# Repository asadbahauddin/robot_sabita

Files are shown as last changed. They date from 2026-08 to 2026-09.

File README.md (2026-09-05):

# SABITA - Robot Pemandu Pameran

Robot line-follower pemandu pameran lukisan (6 karya di node A-F), navigasi
lewat scan QR + rute optimal ACO (Ant Colony Optimization), line-follower
PID adaptif, audio narasi per karya (DFPlayer Mini).

## Arsitektur

Sejak v10, ESP32 **tidak lagi menyajikan HTML**. Semua dashboard/UI pindah
ke laptop supaya beban ESP32 minimal (hanya WiFi AP + WebSocket + motor + sensor).

```
[Sensor S1-S4,S6 (digital), GM67 QR, DFPlayer]
            |
         ESP32  (WiFi AP: SABITA_ROBOT / 12345678)
            |  WebSocket ws://192.168.4.1:81  (data sensor/nav/state/qr/dfp,
            |                                   perintah motor/PID/tuning)
            v
   tools/sabita_server.py   (laptop, relay + serve dashboard + log CSV)
            |  WebSocket ws://localhost:8080/ws
            v
   tools/dashboard.html      (browser laptop: peta, sensor, grafik PID, tuning)
```

`simulasi/` berisi alat terpisah (offline): simulasi rute ACO (GIF) dan
live-monitor alternatif berbasis Python/matplotlib untuk debugging line-follower
langsung dari WebSocket ESP32 tanpa perlu dashboard.html. Lihat bagian
[Alat tambahan](#alat-tambahan-simulasi) di bawah.

## Cara pakai

### 1. Upload firmware ke ESP32

Buka `robot_sabita.ino` di Arduino IDE, pilih board ESP32 yang sesuai, upload.
Pastikan tidak ada file `.ino` lain di folder yang sama (Arduino menggabungkan
semua `.ino` di folder sketch jadi satu build -- itu sebabnya backup lama
disimpan di `backup/*.ino.txt`, bukan `.ino`).

Cek Serial Monitor (115200 baud) untuk konfirmasi `=== READY ===` dan IP AP.

### 2. Sambungkan laptop ke WiFi robot

SSID: `SABITA_ROBOT`, password: `12345678`. ESP32 selalu di `192.168.4.1`.

### 3. Siapkan environment Python (sekali saja)

```
conda create -n sabita_sim python=3.10 -y
conda activate sabita_sim
pip install -r tools/requirements.txt
```

### 4. Jalankan server relay

```
conda activate sabita_sim
python tools/sabita_server.py
```

Opsional: `--esp-host 192.168.4.1 --esp-port 81 --port 8080` (default sudah
sesuai firmware, biasanya tidak perlu diubah).

### 5. Buka dashboard

Browser: **http://localhost:8080**

Dashboard otomatis reconnect baik ke server maupun ke ESP32 kalau salah satu
terputus (lihat 2 indikator titik di header: "Server laptop" & "Robot (ESP32)").

## Fitur dashboard

- **Status & navigasi**: state robot, node sebelumnya/sekarang/berikutnya, nama
  karya, progress, rute ACO.
- **Peta pameran real-time** (canvas): posisi 6 node sesuai banner fisik, edge
  + jarak, node terkunjungi hijau, node aktif pulse merah, rute ACO garis biru
  putus-putus, arah tujuan berikutnya garis oranye putus-putus.
- **Sensor line-follower**: S1-S4,S6 digital (1=kena garis hitam, 0=putih),
  indikator posisi tertimbang (-2..+2, S3=tengah), error & correction PID saat ini.
- **Grafik live** (Chart.js, rolling 5 detik): status digital S1-S4,S6, error vs
  correction, estimasi kecepatan motor kanan/kiri.
- **PID tuning**: slider+input Kp/Ki/Kd, tombol Apply mengirim ke robot,
  ditampilkan juga nilai yang sedang AKTIF di robot (dari telemetry, bukan cuma
  nilai slider) supaya tidak salah kira sudah ter-apply padahal belum.
- **Kontrol**: reset misi, speed (base PID), trim kiri/kanan, volume, stop
  audio, mode pindah manual (tombol arah tanpa perlu scan QR).
- **Log**: riwayat QR ter-scan, tombol download CSV log sensor yang sedang berjalan.

Semua data sensor (setiap ~50ms) otomatis dicatat ke
`tools/logs/robot_log_<waktu>.csv` -- berguna untuk analisis pasca-kejadian
(mis. episode robot bergerak aneh) tanpa harus menonton dashboard secara live.

## Sensor line-follower

Modul **TCRT5000 + LM393** (komparator on-board) -- output digital murni,
threshold diatur lewat trimpot fisik di tiap modul, bukan di software. Firmware
cuma `digitalRead()`, tidak ada lagi ADC/kalibrasi putih-hitam. Konvensi
(dikonfirmasi lewat tes fisik ulang 2026-09-05): **LOW (0) = di atas garis
hitam**, **HIGH (1) = di atas lantai putih**.

Pin: `S1=GPIO33, S2=GPIO32, S3=GPIO35(tengah), S4=GPIO34, S6=GPIO39`.

## Tuning PID line-follower

Formula (lihat `computePID()` di `robot_sabita.ino`):

```
# Posisi = rata-rata tertimbang sensor yg LOW (kena garis), bobot posisi
# fisik -2,-1,0,+1,+2 (S1,S2,S3,S4,S6 -- S3=tengah). Kalau tidak ada sensor
# yg LOW sama sekali (garis hilang), posisi dituntun dari error terakhir yg
# diredam bertahap (bukan reset lurus buta).
position = sum(SENSOR_POS[i] * (sensor[i]==LOW)) / count(sensor[i]==LOW)
error    = position
Kp_eff   = Kp*2.0 jika |error|>1.5, Kp*1.3 jika |error|>0.8, else Kp*1.0
integral = clamp(integral+error, -50, 50)
correction = Kp_eff*error + Ki*integral + Kd*(error-prev_error)
speed_R  = clamp(BASE_SPEED - correction, 0, 255)
speed_L  = clamp(BASE_SPEED + correction, 0, 255)
```

Default: `Kp=30, Ki=0.01, Kd=15, BASE_SPEED=70`. Kalau robot masih berputar-putar
kasar di garis lurus (indikasi sensor cuma kena 1 titik sekaligus, bukan overlap
2 sensor saat belok halus): coba **turunkan Kp** dan/atau **naikkan Kd** dulu
lewat panel PID Tuning sambil lihat grafik error/correction live -- jangan ubah
langsung di firmware, cukup re-upload kalau sudah ketemu angka yang pas dan mau
dijadikan default baru.

## Perintah WebSocket (referensi)

| Perintah | Keterangan |
|---|---|
| `KP:xx`, `KI:xx.xx`, `KD:xx` | Set parameter PID |
| `SPEED:xx` / `BS:xx` | Base speed PID (0-255) -- dua perintah, efek identik |
| `LTRIM:xx`, `RTRIM:xx` | Trim kiri/kanan (-50..50) |
| `VOL:xx` | Volume DFPlayer (0-18) |
| `RESET` | Reset misi ke IDLE |
| `STOP_AUDIO` | Hentikan audio yang sedang main |
| `MANUAL:ON` / `MANUAL:OFF` | Toggle mode pindah manual |
| `M:MAJU` / `M:MUNDUR` / `M:KIRI` / `M:KANAN` / `M:STOP` | Gerak manual (hanya saat `MANUAL:ON`) |

## Alat tambahan (`simulasi/`)

- `sabita_aco_sim.py [START_NODE]` -- simulasi offline: hitung rute ACO
  (parameter identik firmware) dan render animasi GIF.
- `live_monitor.py` -- monitor telemetry live alternatif (matplotlib, tanpa
  browser), dengan strip-chart riwayat sensor dan deteksi otomatis "pembalikan
  arah tajam" -- berguna untuk debug cepat lewat terminal/IDE Python tanpa
  perlu buka dashboard.html. **Catatan**: skrip ini belum diverifikasi ulang
  terhadap skema sensor digital S1-S4,S6 + JSON `jSensor()` terbaru (field
  `r1..r7` sudah tidak dikirim firmware lagi) -- cek dulu sebelum dipakai.

Keduanya pakai environment conda yang sama (`sabita_sim`); install dependency
tambahan dengan `pip install -r simulasi/requirements.txt`.

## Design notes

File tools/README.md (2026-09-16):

# CARA MENJALANKAN SABITA DASHBOARD

1. Connect laptop ke WiFi: **SABITA_ROBOT**
   Password: `12345678`
2. Buka terminal/cmd di folder `robot_sabita`
3. Jalankan: `python tools/sabita_server.py`
4. Buka browser (Chrome/Edge/Firefox biasa -- **bukan** tab "Simple Browser"
   di VS Code) ke: `http://localhost:8080`
   (**JANGAN** buka file `dashboard.html` langsung lewat File Explorer --
   itu tidak akan connect ke server sama sekali)
5. Indikator hijau di pojok kanan atas = terhubung ke server & robot

## Kalau indikator tetap merah

- Pastikan diakses lewat **http://**, bukan **https://** (beberapa browser
  otomatis mengganti ke https -- itu akan memblokir koneksi WebSocket-nya).
- Pastikan pakai browser sungguhan, bukan preview bawaan editor/IDE.
- Cek terminal `sabita_server.py` -- kalau tulisannya `[esp] TERHUBUNG.`
  berarti koneksi ke ESP32 sudah oke, dan masalahnya ada di sisi
  browser->server (bukan ESP32).
- Tekan F12 di browser -> tab Console -> refresh halaman -- kalau ada
  pesan error merah di situ, itu penyebab paling akurat untuk dicari tahu
  lebih lanjut.

## Remote koreksi arah (HP)

Selain dashboard lengkap di atas, ada halaman HP terpisah (2 tombol
kiri/kanan layar penuh) untuk koreksi arah cepat tanpa perlu lihat
dashboard detail. Alamatnya dicetak polos di terminal `sabita_server.py`
begitu server jalan (baris kedua setelah baris dashboard).

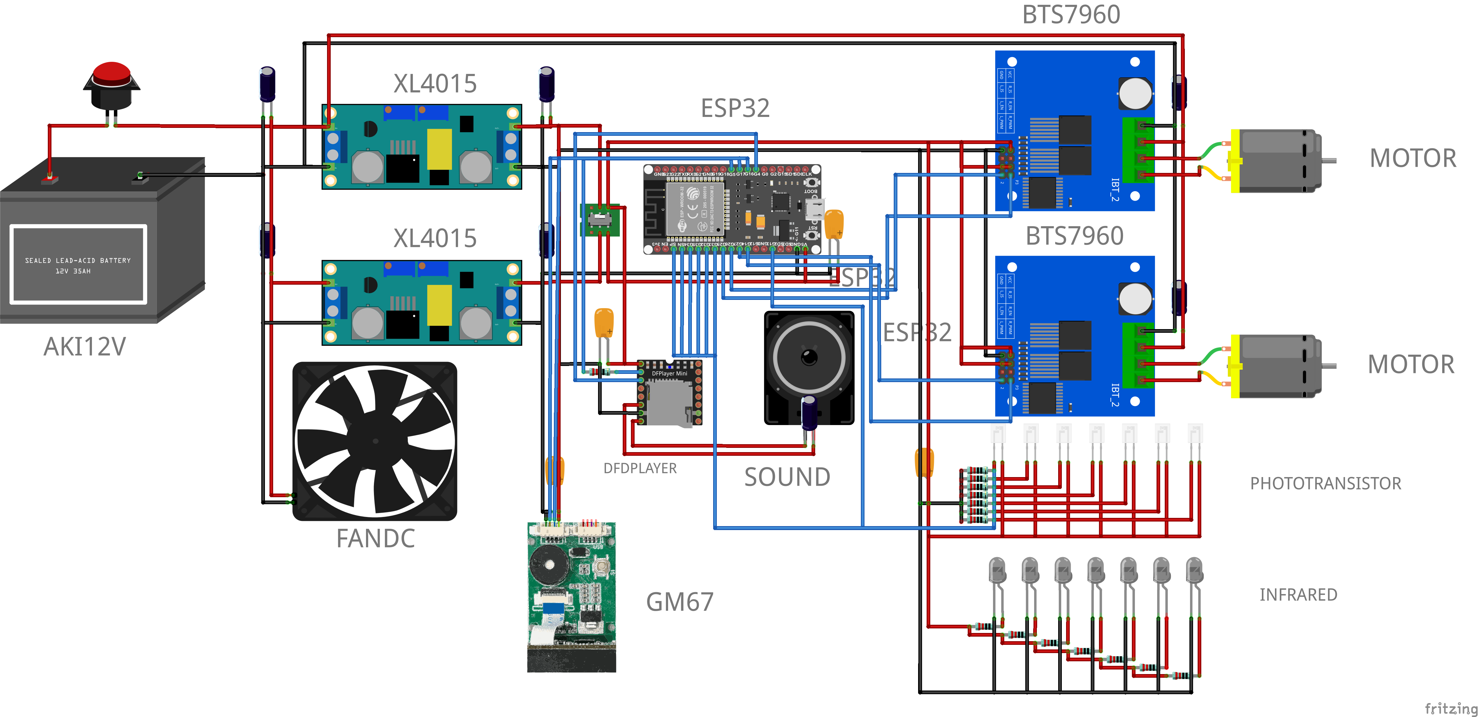
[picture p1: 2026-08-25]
rangkaian terbaru_TSABITA.png

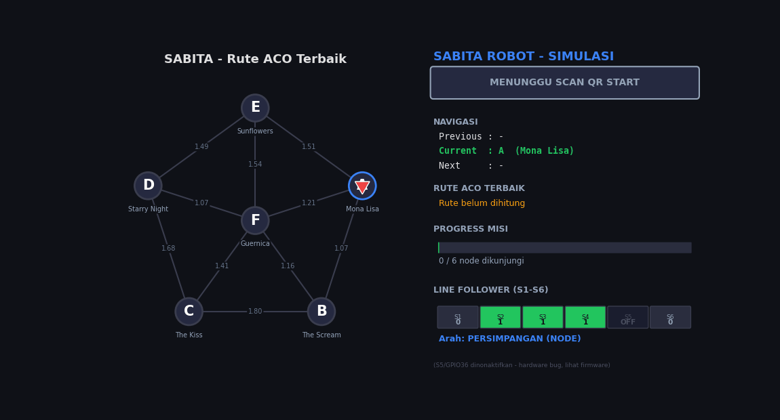
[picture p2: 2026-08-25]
simulasi/sabita_route_simulation.gif

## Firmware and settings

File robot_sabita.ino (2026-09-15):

#include <WiFi.h>
#include <WebSocketsServer.h>
#include <HardwareSerial.h>
#include <DFRobotDFPlayerMini.h>
#include <esp_task_wdt.h>
#include "soc/rtc_cntl_reg.h"  // definisi RTC_CNTL_BROWN_OUT_REG (dipakai di setup() utk matikan brownout detector)

// ============================================================
// SABITA -- firmware HEADLESS. Dashboard HTML jalan di laptop
// (tools/dashboard.html), disajikan oleh tools/sabita_server.py yang
// relay ke ESP32 lewat WebSocket port 81. ESP32 hanya kirim data
// sensor/nav/state/qr/dfp dan terima perintah motor/tuning.
//
// SENSOR LINE FOLLOWER: digital langsung (digitalRead). Modul
// TCRT5000+LM393 (komparator on-board, threshold diatur via trimpot
// fisik di modul, bukan software). Output LM393: DI ATAS PUTIH =
// HIGH(1), DI ATAS HITAM = LOW(0).
// ============================================================

const char* AP_SSID = "SABITA_ROBOT";
const char* AP_PASS = "12345678";

#define MOT_R_RPWM 25
#define MOT_R_LPWM 26
#define MOT_L_RPWM 27
#define MOT_L_LPWM 14
#define PWM_FREQ   5000
#define PWM_RES    8
#define CH_R_RPWM  0
#define CH_R_LPWM  1
#define CH_L_RPWM  2
#define CH_L_LPWM  3

// Motor DC Gearbox 24V, 0.3A, reduksi 27:1. Stall torque 18 kgfcm (cukup
// buat manuver pivot/spin di motorKanan()/motorKiri()), no-load torque
// 7 kgfcm. Kecepatan linear robot terukur ~0.20 m/s pada MOTOR_SPEED=70
// (dari 255). BTS7960 mendukung hingga 43A, jauh di atas kebutuhan arus
// motor, jadi motor aman dijalankan di seluruh rentang PWM 0-255.
int MOTOR_SPEED = 70;   // BASE_SPEED PID (juga dipakai manual drive)
int LEFT_TRIM   = 0;
int RIGHT_TRIM  = 0;

// ===================== SENSOR LINE FOLLOWER (DIGITAL) =====================
// 5 sensor TCRT5000+LM393, urutan kiri->kanan, S3=tengah.
#define PIN_S1 33
#define PIN_S2 32
#define PIN_S3 35
#define PIN_S4 34
#define PIN_S6 39

int sensorPin[5]  = {PIN_S1, PIN_S2, PIN_S3, PIN_S4, PIN_S6};
int sDigital[5]   = {0, 0, 0, 0, 0};
// Posisi fisik tiap sensor (urutan sama dgn sensorPin[]), S3=tengah=0.
const float SENSOR_POS[5] = {-2.0f, -1.0f, 0.0f, 1.0f, 2.0f};

void readSensors() {
  for (int i = 0; i < 5; i++) sDigital[i] = digitalRead(sensorPin[i]);
}

HardwareSerial GM67Serial(2);
HardwareSerial DFPSerial(1);
DFRobotDFPlayerMini dfPlayer;
bool dfReady      = false;
bool audioFinished = true;
unsigned long audioStartMs = 0;   // millis() saat playNode() terakhir memulai audio
int  curVol       = 18;

WebSocketsServer ws(81);

#define N 6
#define F_IDX 5  // indeks 'F' di NNAME[] -- F = hub tengah graf pameran, dipakai computeGeoTurn()
const char  NNAME[N]  = {'A','B','C','D','E','F'};
const char* NART[N]   = {"Mona Lisa","The Scream","The Kiss","Starry Night","Sunflowers","Guernica"};
const char* NDESC[N]  = {
  "Leonardo da Vinci, 1503. Museum Louvre, Paris.",
  "Edvard Munch, 1893. Galeri Nasional, Oslo.",
  "Gustav Klimt, 1907. Museum Belvedere, Wina.",
  "Vincent van Gogh, 1889. Museum MoMA, New York.",
  "Vincent van Gogh, 1888. National Gallery, London.",
  "Pablo Picasso, 1937. Museo Reina Sofia, Madrid."
};

#define INF 999.0f
float D[N][N] = {
  {0,     1.07f, INF,   INF,   1.51f, 1.21f},
  {1.07f, 0,     1.80f, INF,   INF,   1.16f},
  {INF,   1.80f, 0,     1.68f, INF,   1.41f},
  {INF,   INF,   1.68f, 0,     1.49f, 1.07f},
  {1.51f, INF,   INF,   1.49f, 0,     1.54f},
  {1.21f, 1.16f, 1.41f, 1.07f, 1.54f, 0    }
};
float tau[N][N];
int   bestR[N+1];
float bestL = 999999.0f;

// Posisi (x,y) tiap node -- IDENTIK dgn "Graf Pameran (posisi sesuai banner
// fisik)" di dashboard.html & POS di simulasi/sabita_topology.py. Dipakai
// computeGeoTurn() buat menghitung arah belok di tiap node dari geometri
// nyata (bukan tabel manual per-edge) -- lihat computeGeoTurn().
const float POS_X[N] = {1.902f, 1.176f, -1.176f, -1.902f, 0.000f, 0.000f};  // A,B,C,D,E,F
const float POS_Y[N] = {0.618f, -1.618f, -1.618f, 0.618f, 2.000f, 0.000f};  // A,B,C,D,E,F

// Rute rujukan per start node -- siklus Hamiltonian jarak simetris punya
// 2 arah tempuh dgn total jarak identik (mis. A-B-F-C-D-E-A vs
// A-E-D-C-F-B-A, sama2 8.32m), jadi arah hasil ACO perlu disamakan ke
// satu konvensi tetap. ACO tetap dihitung sungguhan (parameter alpha/
// beta/rho/n_ants/n_iter, bestL dari situ -- lihat canonicalizeRoute()),
// tabel ini cuma menentukan ARAH tempuhnya.
// Indeks node: A=0,B=1,C=2,D=3,E=4,F=5 (urutan sama dgn NNAME).
const int CANON_ROUTE[N][N+1] = {
  {0,1,5,2,3,4,0},  // start A: A-B-F-C-D-E-A
  {1,5,2,3,4,0,1},  // start B: B-F-C-D-E-A-B
  {2,3,4,0,1,5,2},  // start C: C-D-E-A-B-F-C
  {3,4,0,1,5,2,3},  // start D: D-E-A-B-F-C-D
  {4,0,1,5,2,3,4},  // start E: E-A-B-F-C-D-E
  {5,1,0,4,3,2,5},  // start F: F-B-A-E-D-C-F
};

// Timpa arah bestR[] (hasil runACO() yg BENERAN dihitung) supaya SELALU
// sesuai tabel rujukan di atas -- bestL TIDAK diubah (tetap dari runACO(),
// krn kedua arah jaraknya identik jadi tetap valid).
void canonicalizeRoute(int start){
  for (int i=0; i<=N; i++) bestR[i] = CANON_ROUTE[start][i];
}

// Rute aktual (nyata) yg dilalui robot, buat dibandingkan dgn rute ACO
// optimal (bestR/bestL) begitu misi FINISHED.
int   actual_route[N+1];
int   actual_route_len = 0;
float actual_distance  = 0.0f;

// Parameter ACO (spesifikasi): alpha=1, beta=2, rho=0.3, n_ants=6, n_iter=100
#define ACO_ALPHA  1.0f
#define ACO_BETA   2.0f
#define ACO_RHO    0.3f
#define ACO_NANTS  6
#define ACO_NITER  100

enum State { IDLE, ARRIVED, MOVING };
State robotState  = IDLE;
bool manualMode   = false;   // Mode pindah robot manual lewat dashboard
unsigned long arrTime = 0;

bool  visited[N];
int   nVisited = 0;
int   startIdx = -1;
int   prevIdx  = -1;
int   currIdx  = -1;
int   nextIdx  = -1;
int   stepIdx  = 0;

unsigned long lastSensor = 0;
#define SENSOR_INTERVAL_MS 50

String pendingQR = "";
unsigned long pendingQRTime = 0;
#define NODEZONE_TIMEOUT_MS 2000

// ===================== LINE FOLLOWER: BANG-BANG =================
// Kontrol on/off sederhana berdasarkan pola 5 sensor digital, bukan PID.
//
// Kp/Ki/Kd tidak dipakai lineFollow() (dibiarkan ada cuma supaya perintah
// WS KP:/KI:/KD: & field JSON kp/ki/kd tetap valid untuk kompatibilitas
// dashboard).
float Kp = 15.0f, Ki = 0.01f, Kd = 8.0f;
float gLastPos = 0.0f, gLastErr = 0.0f, gLastCorr = 0.0f;  // sekarang statis/tidak dipakai lineFollow(), dibiarkan buat JSON pos/err/corr
String gLastMode = "OFF";
String prevMode  = "";  // buat deteksi transisi mode -- broadcast cuma pas berubah, bukan tiap loop()
int gSpeedR = 0, gSpeedL = 0;  // PWM motor R/L TERAKHIR yg BENAR2 dikirim ledcWrite()

// Recovery saat garis hilang total (semua sensor putih) -- lihat lineFollow().
// Arah cari selalu ke kanan (motorKanan()), deterministik, tidak tergantung
// riwayat gerak sebelumnya.
unsigned long lostSince = 0;   // millis() saat garis pertama kali hilang, 0=lagi tidak hilang

// "Salah node" (nyasar ke cabang persimpangan yg salah) -- lihat loop()/case
// MOVING. Begitu QR yg kebaca BUKAN nextIdx (node yg direncanakan ACO), robot
// TIDAK dianggap sampai (bukan onArrived()), tapi putar balik otomatis &
// coba lagi menuju nextIdx yg sama.
unsigned long turnAroundUntil = 0;  // selagi millis()<ini, motor di-override "putar balik", bukan lineFollow() biasa
bool turningAround = false;          // true selama proses putar balik (biar bisa kirim ulang state MOVING pas selesai)
int wrongNodeRetries = 0;            // reset di onArrived() (sukses) & resetPID()
bool stuckWrongNode = false;         // true stlh retry abis -- robot berhenti total, butuh intervensi manual (MANUAL:ON / RESET)

// "Nudge" manual tanpa masuk mode manual penuh: operator bisa tekan tombol
// panah di dashboard/remote (M:MAJU/M:MUNDUR/M:KIRI/M:KANAN) sambil robot
// masih MOVING otomatis, buat koreksi arah langsung. Sensor QR/FSM/audio
// tetap jalan normal di belakang layar -- ini cuma override motor
// sementara.
bool userNudge = false;   // true selama tombol ditekan (M:STOP saat dilepas -> false lagi)
int userNudgeDir = 0;     // 1=maju, -1=mundur, 2=kanan, -2=kiri, 0=tidak ada nudge

// Belok terjadwal di persimpangan: robot berputar di tempat (motorKanan()/
// motorKiri()) selama durasi tertentu (timer), dijadwalkan begitu MOVING
// dimulai lalu dieksekusi begitu sensor mendeteksi persimpangan fisik
// (S1 dan S6 sama-sama hitam) -- bukan tepat di titik keberangkatan, krn
// persimpangan biasanya ada di tengah perjalanan menuju node berikutnya.
// "Diarm" dulu (geoTurnArmed) setelah robot terlihat di jalur normal
// terus-menerus >= GEO_TURN_ARM_MS, supaya zona node yang baru saja
// ditinggalkan tidak langsung memicu belokan sebelum robot berangkat.
// Tambahan di atas line-follower/recovery yang sudah ada, bukan pengganti.
unsigned long geoTurnUntil = 0;   // selagi millis()<ini, motor di-override belok terjadwal (bukan lineFollow() biasa)
int geoTurnDir = 0;               // +1=kanan(motorKanan), -1=kiri(motorKiri), 0=tidak ada belok terjadwal
bool geoTurnPending = false;      // true = ada belokan terjadwal, NUNGGU persimpangan fisik terdeteksi
bool geoTurnArmed = false;        // true = robot sudah kelihatan bener2 di jalur normal (bkn zona keberangkatan sendiri), trigger boleh nyala
unsigned long geoTurnClearSince = 0;    // millis() sejak MULAI terus-menerus di jalur normal (hitCount<3)
unsigned long geoTurnDurationMs = 0;    // durasi manuver, dipakai begitu trigger nyala
float geoTurnAngleDeg = 0.0f;           // sudut belok terjadwal terakhir dihitung (0=hop ini gak ada belok) -- buat telemetry/CSV

// ===== Parameter gerak yg bisa di-TUNING LIVE lewat WS (TANPA upload ulang
// firmware) -- lihat handler pesan WS di wsEvent(). sabita_server.py bisa
// dorong nilai baru kapan saja lewat TUNABLE_PARAMS (termasuk otomatis
// tiap ESP32 reconnect). Struktur/algoritma line-follower tetap butuh
// upload ulang -- ini cuma angka-angkanya.
int SPD_STRAIGHT     = 70;   // PWM lurus (S3)
int SPD_GENTLE_FAST  = 70;   // PWM sisi cepat saat koreksi ringan (S2/S4)
int SPD_GENTLE_SLOW  = 30;   // PWM sisi lambat saat koreksi ringan (S2/S4)
int SPD_SHARP_SLOW   = 20;   // PWM sisi lambat saat belok tajam (S1/S6) -- sisi cepatnya pakai MOTOR_SPEED (perintah SPEED:)
int SPD_SEARCH_CREEP = 35;   // PWM maju pelan saat garis baru hilang (< LOST_PHASE1_MS)
unsigned long LOST_PHASE1_MS = 300;    // di bawah ini sejak garis hilang: maju pelan (mungkin cuma celah kecil); di atasnya: cari ke kanan TANPA BATAS WAKTU
unsigned long TURN_AROUND_MS = 900;    // durasi putar ~180 derajat, OPEN-LOOP (tdk ada sensor arah) -- HASIL TES FISIK (waktu 360 derajat / 2)
int WRONG_NODE_MAX_RETRIES   = 3;      // biar gak puter2 selamanya kalau memang salah terus
bool  ENABLE_GEO_TURN   = true;   // matikan cepat lewat Python (GEOTURN:0) kalau ternyata meleset, TANPA reflash -- lihat computeGeoTurn()
float GEO_TURN_MIN_DEG  = 20.0f;  // di bawah sudut ini (hampir lurus) TIDAK usah belok terjadwal, biarkan lineFollow() saja
unsigned long GEO_TURN_ARM_MS = 400;  // minimal waktu terus-menerus di jalur normal sblm trigger persimpangan boleh nyala (hindari kepicu zona keberangkatan sendiri)
unsigned long ARRIVED_MIN_DWELL_MS = 3000;  // jeda minimum di tiap node walau audioFinished sudah true dari awal (mis. DFPlayer tidak siap) -- robot tidak langsung lanjut MOVING tanpa jeda sama sekali
unsigned long AUDIO_TIMEOUT_MS  = 15000;  // batas atas nunggu audio kalau sinyal "selesai" dari DFPlayer gak pernah datang (mis. audio asli lebih panjang dari perkiraan)
unsigned long AUDIO_MIN_PLAY_MS = 3000;   // sinyal "selesai" dari DFPlayer diabaikan kalau datang lebih cepat dari ini sejak play() -- filter sinyal palsu/noise

// Diset true saat QR ter-scan ketika robotState==MOVING (di loop()); dipakai
// buat pelan-pelan sesaat sebelum sampai node. Direset di onArrived().
// (bagian dari logika QR yg TIDAK diubah -- sekarang tidak dibaca lineFollow()
// lagi, tapi variabelnya dibiarkan supaya blok QR di loop() tidak perlu diubah.)
bool  approaching_node = false;

void resetPID(){
  gLastMode = "OFF";
  lostSince = 0;
  turnAroundUntil = 0;
  turningAround = false;
  wrongNodeRetries = 0;
  stuckWrongNode = false;
  geoTurnUntil = 0;
  geoTurnDir = 0;
  geoTurnPending = false;
  geoTurnArmed = false;
  geoTurnClearSince = 0;
  geoTurnDurationMs = 0;
  geoTurnAngleDeg = 0.0f;
  userNudge = false;
  userNudgeDir = 0;
}
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
void loop(){
  ws.loop();
  readSensors();

  int s1=sDigital[0],s2=sDigital[1],s3=sDigital[2],s4=sDigital[3],s6=sDigital[4];

  bool driving = (!manualMode && robotState==MOVING);
  if(driving) {
    // Belok terjadwal (geoTurnPending) BARU dipicu begitu sensor BENAR2
    // mendeteksi persimpangan (>=3 sensor hitam) DI TENGAH perjalanan --
    // bukan tepat di keberangkatan (lihat catatan panjang di deklarasi
    // geoTurnPending). "Diarm" dulu (geoTurnArmed) setelah robot terlihat
    // di jalur normal terus-menerus >= GEO_TURN_ARM_MS, supaya zona node
    // yg BARU SAJA ditinggalkan (juga >=3 sensor hitam) tidak langsung
    // memicu belokan sebelum robot benar2 berangkat.
    if (geoTurnPending) {
      // Persimpangan fisik (marka lebar) kena di kedua sensor ujung (S1 &
      // S6) sekaligus -- tikungan biasa (sekencang apa pun) cuma narik
      // salah satu sisi, jadi ini pembeda yg reliabel antara keduanya.
      bool persimpangan = (s1==0) && (s6==0);
      if (persimpangan) {
        if (geoTurnArmed) {
          // Persimpangan BERIKUTNYA (bukan zona keberangkatan sendiri) -- picu!
          geoTurnPending = false; geoTurnArmed = false; geoTurnClearSince = 0;
          geoTurnUntil = millis() + geoTurnDurationMs;
          Serial.printf("GeoTurn TERPICU @ persimpangan: arah=%s durasi=%lums\n",
            geoTurnDir>0?"KANAN":"KIRI", geoTurnDurationMs);
        } else {
          geoTurnClearSince = 0;  // masih zona keberangkatan -- reset penghitung "jalur bersih"
        }
      } else {
        if (geoTurnClearSince == 0) geoTurnClearSince = millis();
        if (!geoTurnArmed && millis()-geoTurnClearSince >= GEO_TURN_ARM_MS) geoTurnArmed = true;
      }
    }

    if (userNudge) {
      // Operator lagi koreksi manual pakai tombol panah (M:MAJU/MUNDUR/
      // KIRI/KANAN dikirim di startNudge(), motor sudah didrive langsung
      // di situ) -- PALING PRIORITAS drpd override otomatis lain. Di sini
      // cuma jaga supaya lineFollow()/dll TIDAK menimpa tiap loop()
      // iterasi selama tombol masih ditekan (M:STOP saat dilepas ->
      // userNudge=false lagi, lihat wsEvent()).
    } else if (stuckWrongNode) {
      // Sudah gagal WRONG_NODE_MAX_RETRIES kali -- menyerah, berhenti total
      // (bukan coba lagi selamanya), butuh intervensi manual.
      motorStop();
      gLastMode="STUCK"; gSpeedR=0; gSpeedL=0;
      reportPidMode();
    } else if (millis() < turnAroundUntil) {
      // Lagi putar balik otomatis (salah node -- lihat case MOVING di bawah).
      // Arah putar SENGAJA tetap/konsisten (motorKanan()), bukan tergantung
      // lastTurnDir, biar durasi TURN_AROUND_MS bisa diandalkan/di-tune.
      motorKanan();
      gLastMode="TURNAROUND"; gSpeedR=MOTOR_SPEED; gSpeedL=-MOTOR_SPEED;
      reportPidMode();
    } else if (millis() < geoTurnUntil) {
      // Belok terjadwal ke node berikutnya (arah+durasi dihitung sekali
      // di computeGeoTurn() begitu MOVING dimulai, dari geometri Graf
      // Pameran, TAPI baru dieksekusi begitu persimpangan fisik
      // terdeteksi -- lihat blok geoTurnPending di atas) -- TAMBAHAN,
      // bukan pengganti lineFollow() normal yg dilanjutkan sesudahnya.
      if (geoTurnDir > 0) { motorKanan(); gSpeedR=MOTOR_SPEED; gSpeedL=-MOTOR_SPEED; }
      else                { motorKiri();  gSpeedR=-MOTOR_SPEED; gSpeedL=MOTOR_SPEED; }
      gLastMode="GEOTURN";
      reportPidMode();
    } else {
      if (turningAround) {
        // Putar balik baru saja selesai -- kirim ulang state MOVING supaya
        // dashboard keluar dari tampilan WRONG_NODE.
        turningAround = false;
        String s=jState("MOVING"); bcast(s);
      }
      lineFollow();
    }
  } else if (gLastMode != "OFF") {
    // Motor sudah dihentikan terpisah lewat motorStop() di FSM (IDLE/ARRIVED)
    // -- ini cuma supaya telemetry (mode/speedR/speedL di dashboard) tidak
    // nyangkut di "BANGBANG" pas robot sebenarnya sudah berhenti.
    gLastMode = "OFF"; gSpeedR = 0; gSpeedL = 0;
    reportPidMode();
  }

  if(millis()-lastSensor>=SENSOR_INTERVAL_MS){
    lastSensor=millis();
    // l1..l6 = true kalau sensor itu KENA GARIS (LOW=0, dikonfirmasi tes fisik ulang).
    bool l1=(s1==0), l2=(s2==0), l3=(s3==0), l4=(s4==0), l6=(s6==0);
    int hitCount = (l1?1:0)+(l2?1:0)+(l3?1:0)+(l4?1:0)+(l6?1:0);
    String arah="TIDAK ADA GARIS";
    if(hitCount>=3)         arah="PERSIMPANGAN";
    else if(l3&&!l2&&!l4)   arah="LURUS";
    else if(l2&&l3)         arah="BELOK KIRI";
    else if(l3&&l4)         arah="BELOK KANAN";
    else if(l1||l2)         arah="KIRI TAJAM";
    else if(l4||l6)         arah="KANAN TAJAM";
    unsigned long lostMs = (lostSince>0) ? (millis()-lostSince) : 0;
    String sj=jSensor(s1,s2,s3,s4,s6,arah,gLastPos,gLastErr,gLastCorr,gLastMode,gSpeedR,gSpeedL,lostMs);
    bcast(sj);
  }

  if(manualMode){
    // Selama manual, QR/nodeZone SENGAJA tidak disentuh sama sekali (bukan
    // cuma "return setelah dibaca") -- kalau ini dilakukan setelah pendingQR
    // sudah dikonsumsi jadi qrToProcess, scan yang kebetulan siap diproses
    // pas robot lagi digerakkan manual bisa hilang percuma (dikonsumsi lalu
    // dibuang oleh return, padahal belum sempat memicu onArrived()).
    return;
  }

  // Node fisik = area lebar yang menyalakan banyak sensor sekaligus (mirip
  // PERSIMPANGAN). QR DIPRIORITASKAN dipakai untuk navigasi begitu robot
  // memang di zona itu -- tapi kalau marka fisik ternyata tidak cukup lebar
  // untuk menyalakan >=3 sensor, QR tetap diproses lewat fallback timeout
  // di bawah supaya scan valid tidak pernah diabaikan selamanya.
  int nodeZoneCount = (s1==0)+(s2==0)+(s3==0)+(s4==0)+(s6==0);
  bool nodeZone = (nodeZoneCount >= 3);

  String qr="";
  if(GM67Serial.available()){
    unsigned long t=millis();
    while(millis()-t<200){
      if(GM67Serial.available()){
        char c=GM67Serial.read();
        if(c=='\r'||c=='\n'){if(qr.length()>0)break;}
        else qr+=c;
        t=millis();
      }
    }
    if(qr.length()>0){
      Serial.println("QR: "+qr);
      String qj=jQR(qr); bcast(qj);  // selalu ditampilkan di riwayat dashboard
      if(robotState==MOVING) approaching_node=true;  // pelan-pelan sesaat sebelum sampai node
      if(pendingQR.length()==0 || pendingQR!=qr){
        // Timer cuma dimulai/direset kalau ini kode BARU (beda dari yang
        // sedang pending). GM67 biasa membaca ulang kode yang sama berkali-
        // kali selama masih menyorot -- kalau timer direset tiap scan ulang,
        // timeout NODEZONE_TIMEOUT_MS tidak akan pernah tercapai dan robot
        // macet permanen di IDLE walau QR sudah kebaca sejak lama.
        pendingQR=qr; pendingQRTime=millis();
      }
    }
  }

  // Proses pendingQR begitu nodeZone true, ATAU setelah NODEZONE_TIMEOUT_MS
  // tanpa nodeZone sama sekali (fallback -- jangan sampai QR valid terbuang).
  String qrToProcess="";
  if(pendingQR.length()>0 && (nodeZone || millis()-pendingQRTime>=NODEZONE_TIMEOUT_MS)){
    qrToProcess=pendingQR;
    pendingQR="";
  }

  switch(robotState){

    case IDLE:
      motorStop();
      if(qrToProcess.length()>0){
        int idx=parseNode(qrToProcess);
        if(idx>=0){
          startIdx=idx;
          Serial.println("Start: Node "+String(NNAME[idx]));
          // ACO dihitung langsung dari node start -- rute & nextIdx
          // langsung diketahui sejak hop pertama, jadi deteksi salah-node
          // & belok terjadwal (computeGeoTurn(), mulai aktif dari hop
          // ke-2 krn hop pertama belum punya arah datang) bisa siap lebih
          // awal.
          Serial.println("Hitung ACO dari start...");
          unsigned long t0=millis();
          bool ok=runACO(idx);
          Serial.println("ACO "+String(millis()-t0)+"ms");
          if(ok){
            canonicalizeRoute(idx);  // samakan arah ke tabel rujukan yg dikonfirmasi client
            Serial.print("Rute: ");
            for(int i=0;i<=N;i++){Serial.print(NNAME[bestR[i]]);if(i<N)Serial.print("-");}
            Serial.println(" "+String(bestL,2)+"m");
            String rt=jRoute(); bcast(rt);
          }
          onArrived(idx);
        }
      }
      break;
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

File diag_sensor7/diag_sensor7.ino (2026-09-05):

// ============================================================
// SABITA - Diagnostik Sensor Line Follower (S1-S7 mentah)
// ============================================================
// Sketch TERPISAH dari robot_sabita.ino (folder beda sengaja, supaya
// Arduino IDE tidak menggabungkan dua .ino jadi satu build).
//
// Tujuan: baca ke-7 slot sensor sesuai URUTAN FISIK BOARD (S1..S7),
// bukan urutan/penamaan yang dipakai robot_sabita.ino sekarang (itu
// sudah direlabel karena salah satu sensor dipindah posisi fisik).
// Tidak ada WebSocket/dashboard/motor/DFPlayer/QR/ACO -- murni baca
// ADC mentah, cetak ke Serial Monitor.
//
// CARA PAKAI:
//   1. Upload sketch ini ke ESP32 (bukan robot_sabita.ino).
//   2. Buka Serial Monitor, 115200 baud.
//   3. Usap/tutup jari di atas tiap sensor fisik SATU PER SATU (S1 dulu,
//      lanjut S2, dst) sambil lihat kolom mana yang nilainya berubah.
//   4. Kolom yang TIDAK PERNAH berubah sama sekali walau disentuh
//      langsung = bermasalah secara fisik (kabel/solderan/komponen).
//   5. Kolom S7 KHUSUS: nilainya memang akan lompat-lompat tidak stabil
//      terus-menerus (bukan cuma diam di 0) -- itu bukan sensor rusak,
//      itu GPIO13 = ADC2 yang konflik dengan radio WiFi AP yang sengaja
//      dinyalakan di sketch ini. Jangan dipakai untuk diagnosis fisik.

#include "driver/adc.h"
#include <WiFi.h>

// WiFi AP dinyalakan SENGAJA (SSID/password sama seperti robot_sabita.ino)
// supaya kondisi tes identik dengan operasi normal robot -- termasuk
// konflik ADC2 (S7) dan erratum WiFi-noise di ADC1 CH0/CH3 (S5=GPIO39,
// S6=GPIO36) yang cuma muncul kalau WiFi benar-benar aktif.
const char* AP_SSID = "SABITA_ROBOT";
const char* AP_PASS = "12345678";

// Urutan fisik board: S1..S7 kiri->kanan (lihat catatan GPIO13/ADC2 di atas)
#define PIN_S1 33
#define PIN_S2 32
#define PIN_S3 35
#define PIN_S4 34
#define PIN_S5 39
#define PIN_S6 36
#define PIN_S7 13

const int SENSOR_PIN[7] = {PIN_S1, PIN_S2, PIN_S3, PIN_S4, PIN_S5, PIN_S6, PIN_S7};
const char* SENSOR_LABEL[7] = {"S1(33)", "S2(32)", "S3(35)", "S4(34)", "S5(39)", "S6(36)", "S7(13)"};

#define ADC_OS 8  // oversampling, sama seperti readADC() di robot_sabita.ino

int readADC(int pin) {
  long s = 0;
  for (int i = 0; i < ADC_OS; i++) { s += analogRead(pin); delayMicroseconds(50); }
  return s / ADC_OS;
}

unsigned long lastPrint = 0;

void setup() {
  Serial.begin(115200);
  delay(200);
  Serial.println("\n=== SABITA - Diagnostik Sensor S1-S7 ===");

  adc_power_acquire();           // sama seperti robot_sabita.ino (mitigasi erratum GPIO36/39)
  analogReadResolution(12);
  analogSetAttenuation(ADC_11db);

  WiFi.mode(WIFI_AP);
  delay(100);
  WiFi.softAP(AP_SSID, AP_PASS);
  delay(500);
  Serial.println("WiFi AP aktif: " + String(AP_SSID) + " (" + WiFi.softAPIP().toString() + ")");

  Serial.println("S7(GPIO13)=ADC2, TIDAK VALID selama WiFi AP aktif (limitasi hardware");
  Serial.println("ESP32) -- nilainya cuma buat pembanding visual, abaikan untuk diagnosis");
  Serial.println("sensor fisik. Kolom lain (S1-S6) itu ADC1, valid dites walau WiFi nyala.\n");

  Serial.println("Usap/tutup jari di atas tiap sensor satu per satu, amati kolom mana yang berubah...\n");
}

void loop() {
  if (millis() - lastPrint >= 200) {
    lastPrint = millis();
    String line = "";
    for (int i = 0; i < 7; i++) {
      int val = readADC(SENSOR_PIN[i]);
      line += String(SENSOR_LABEL[i]) + "=" + String(val);
      if (i < 6) line += "  ";
    }
    Serial.println(line);
  }
}

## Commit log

2026-08-25 Initial commit: SABITA robot pemandu pameran
    Firmware ESP32 (line-follower PID adaptif, ACO routing, QR node detection)
    plus tooling laptop (dashboard live telemetry, relay server, simulasi ACO).
    [log sensor dari kanan kekiri melewati garis hitam.csv, log sensor putih semuanya.csv, rangkaian terbaru.fzz]
2026-09-05 Ganti sensor line-follower ke digital TCRT5000+LM393, tambah pencarian aktif & perbandingan rute
    - Sensor: dari ADC analog+kalibrasi (6ch) ke digitalRead murni (5ch: S1,S2,S3,S4,S6),
    polaritas dikonfirmasi tes fisik: LOW=garis hitam, HIGH=putih
    - computePID(): weighted centroid diskrit dgn bobot -2..+2, gain adaptif per |error|
    - Penanganan area node lebar (total>=4 sensor): jalan lurus pelan, tandai node_crossing
    - Garis hilang total: redam correction bertahap (bukan tahan permanen -- cegah robot
    spiral menjauh saat garis hilang di tengah tikungan tajam)
    - Pencarian aktif: kalau garis masih hilang setelah fase redam, robot berbelok ke arah
    sensor hitam terakhir sampai ketemu lagi (buk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
    [diag_sensor7.ino, robot_sabita.ino]
2026-09-14 Line follower jalan (fix tukar-kanal R/L) + recovery cari garis, dashboard record/replay & timer, tools estimasi & simulator
    - robot_sabita.ino: perbaiki bug channel CH_R_*/CH_L_* yang tertukar dari
    label kanan/kiri fisik (dikonfirmasi tes fisik langsung) -- ini akar
    masalah "robot menghindari garis" yang sebelumnya diduga bug PID.
    Tambah recovery pencarian garis (lastTurnDir/lostSince) saat semua
    sensor putih, alih-alih cuma jalan lurus terus. Tambah field lost_ms
    di telemetry sensor.
    - tools/sabita_server.py: rekam semua pesan ESP32 ke logs/session_*.json
    (buat fitur replay dashboard), kolom "marker" di CSV + command MARKER:
    buat sinkronisasi log dengan rekaman video.
    - tools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
    [robot_sabita.ino]
2026-09-14 Ganti timeout menyerah cari-garis dari spin tanpa batas jadi 1 detik
    Setelah lostSince>=1000ms tanpa ketemu garis, robot berhenti total &
    lapor mode "LOST" ke dashboard/CSV, bukan spin di tempat selamanya.
    Kalau digeser balik ke atas garis, otomatis pulih ke BANGBANG lagi
    tanpa perlu reset manual (lostSince=0 pas garis ketemu lagi).
    [robot_sabita.ino]
2026-09-14 Deteksi salah node di persimpangan + putar balik otomatis
    Kalau QR yang kebaca di MOVING BUKAN nextIdx (node yang direncanakan
    ACO), robot TIDAK dianggap sampai (audio tidak diputar, node tidak
    ditandai visited) -- putar balik ~180 derajat (open-loop, TUNE
    TURN_AROUND_MS sesuai robot asli), lalu line-follow lagi menuju node
    yang sama. Broadcast state "WRONG_NODE" (got/expected) supaya
    kelihatan di dashboard tanpa perlu ubah dashboard.html.
    Dibatasi WRONG_NODE_MAX_RETRIES=3 -- kalau tetap gagal, robot berhenti
    total & lapor "STUCK", butuh intervensi manual (MANUAL:ON / RESET),
    supaya tidak puter-puter selamanya kalau memang ada masalah struktural.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
    [robot_sabita.ino]
2026-09-14 Dokumentasi karakterisasi motor/roda (PG36 24V) + turunkan ROBOT_SPEED_MS dari formula PWM
    Motor DC Gearbox 24V 0.3A, 4 varian RPM (43/120/222/462, reduksi
    139:1/50:1/27:1/13:1). Dari kecepatan terukur ~0.20 m/s di PWM=70 dan
    asumsi hubungan PWM->kecepatan linear, v_max~=0.73 m/s -- paling dekat
    varian 222 RPM (v_max teoritis 0.755 m/s, roda 65mm). Tambah
    speed_for_pwm() di sabita_estimasi.py & sabita_simulator.py supaya
    ROBOT_SPEED_MS diturunkan dari formula (bukan angka tebakan lepas),
    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
2026-09-14 Jadikan parameter gerak line-follower live-tunable lewat WS (tanpa upload ulang)
    robot_sabita.ino: ubah angka PWM bang-bang (lurus/koreksi/belok tajam/
    search-creep), ambang waktu lost-line (fase1/giveup), TURN_AROUND_MS,
    dan WRONG_NODE_MAX_RETRIES dari literal/#define jadi variabel, plus
    handler WS command baru buat tiap satu (mis. SPD_STRAIGHT:70). Tidak
    ada perubahan perilaku default -- nilai awal sama persis seperti
    sebelumnya.
    tools/sabita_server.py: tambah TUNABLE_PARAMS -- dorong otomatis ke
    ESP32 tiap kali connect/reconnect, jadi tuning gerak (termasuk hasil
    tes fisik TURN_AROUND_MS nanti) cukup edit satu file Python + restart
    server, tidak perlu colok USB & upload ulang firmware. D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
    [robot_sabita.ino]
2026-09-14 Koreksi kecepatan & TURN_AROUND_MS dari hasil tes fisik lab (cuma Python, ESP32 tidak disentuh)
    Hasil tes lab (jalan 1m 3x, putar 180 derajat 3x, putar 360 derajat
    3x, jarak antar roda 41cm):
    - v(PWM=70) = 0.0548 m/s (dari rata2 18.23s/meter) -- jauh lebih lambat
    dari perkiraan lama 0.20 m/s. Ternyata "0.20 m/s" yang dikira v di
    PWM=70 itu justru lebih dekat ke v_max (PWM=255) yang sebenarnya:
    v_max terkoreksi jadi 0.1998 m/s (dari 0.73 m/s sebelumnya).
    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
2026-09-14 Sederhanakan arah cari-garis: selalu ke kanan, bukan nebak dari riwayat belok
    Ganti logika Fase 2 di lineFollow() (garis hilang total) dari
    "spin ke arah lastTurnDir terakhir" jadi SELALU motorKanan() --
    deterministik, tidak lagi bisa salah tebak arah dari riwayat sensor
    sebelumnya. Sesuai instruksi user: "kalau line followernya keluar
    garis, robot langsung gerak kekanan sampai ketemu garis".
    Variabel lastTurnDir & blok tracking-nya dihapus krn jadi dead code
    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
2026-09-14 Hapus batas waktu menyerah saat cari garis -- putar kanan terus sampai ketemu
    Sesuai instruksi user: "kalau keluar garis, putar sampai ketemu garis"
    (tanpa batas waktu). Hapus fase "LOST" (berhenti total setelah 1 detik)
    yang sebelumnya ditambahkan -- sekarang Fase 2 (cari ke kanan) tidak
    ada batas atas lagi, robot spin motorKanan() terus sampai sensor
    mendeteksi garis lagi, seberapa pun lama itu.
    Hapus juga variabel LOST_GIVEUP_MS, handler WS-nya, dan entry di
    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
2026-09-14 Belok terjadwal di persimpangan (dihitung dari geometri Graf Pameran) + fix bug rute ACO start=F
    FITUR BARU -- belok terarah tambahan (bukan pengganti line-follower/
    recovery yg sudah ada): begitu MOVING dimulai & prevIdx/currIdx/nextIdx
    diketahui, computeGeoTurn() menghitung sudut belok dari POS_X/POS_Y
    (koordinat node, identik "Graf Pameran" di dashboard.html) lewat
    cross/dot product vektor arah masuk & keluar -- durasi manuver
    proporsional dari TURN_AROUND_MS yg sudah dikalibrasi fisik. Divalidasi
    matematis vs contoh user (A->B->F = belok KANAN, cocok persis).
    Hop pertama (blm ada arah masuk) & hop terakhir (misi selesai) sengaja
    tidak dapat belok terjadwal. ENABLE_GEO_TURN/GEO_TURN_MIN_D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
    [robot_sabita.ino]
2026-09-14 Hitung ACO langsung dari node start, bukan nunggu node ke-2
    Sesuai instruksi user 2026-09-15. Sebelumnya ACO baru dihitung begitu
    node KE-2 terdeteksi (nextIdx tetap -1 selama hop pertama). Sekarang
    runACO() dipanggil di case IDLE begitu QR node start ke-scan --
    onArrived() sudah otomatis pakai bestR[] buat set nextIdx (logikanya
    tidak diubah), jadi nextIdx & rute ACO langsung valid sejak hop
    pertama. Manfaatnya: deteksi salah-node & belok terjadwal
    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
2026-09-14 Fix belok terjadwal: eksekusi begitu persimpangan fisik TERDETEKSI, bukan pakai timer dari keberangkatan
    Bug dari implementasi geo-turn sebelumnya: belokan dieksekusi LANGSUNG
    begitu MOVING mulai (durasi dari TURN_AROUND_MS/sudut, dihitung dari
    titik keberangkatan) -- ternyata salah, karena persimpangan fisik ke
    arah tujuan (mis. menuju F) ada DI TENGAH perjalanan, bukan tepat di
    titik berangkat. Akibatnya timer keburu habis & robot sudah lanjut ke
    jalur lain (mis. ke arah C) sebelum benar-benar sampai di persimpangan
    yang dimaksud -- persis dilaporkan user.
    Fix: arah+durasi tetap dihitung sekali di computeGeoTurn() (geometri
    Graf Pameran, sama seperti sebelumnya), tapi sekarang DITUNGGU
    (g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
    [robot_sabita.ino]
2026-09-14 Deteksi arah siklus ACO kebalik (2 arah sama-sama optimal) -- jangan anggap salah node
    Bug ditemukan dari laporan user: scan A, next seharusnya B (per pola
    rute optimal A-B-F-C-D-E-A), tapi ACO menghasilkan next=E. Ternyata
    BUKAN bug hitung -- siklus Hamiltonian jarak simetris SELALU punya 2
    arah tempuh dgn total jarak IDENTIK (A-B-F-C-D-E-A dan A-E-D-C-F-B-A
    sama-sama 8.32m), dan runACO() yg stokastik gak ada alasan konsisten
    milih salah satu arah tiap kali dihitung.
    Sebelum fix ini: kalau robot fisik cuma bisa ke arah yg "salah" (mis.
    B) sementara ACO expect arah lain (E), sistem wrong-node akan
    menganggapnya kesalahan & paksa putar-balik yg tidak perlu.
    Fix: di case MOVING, kalau node y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
    [robot_sabita.ino]
2026-09-14 Paksa arah rute ACO sesuai tabel rujukan yang dikonfirmasi client
    Sebelumnya (komit lalu) cuma deteksi & koreksi REAKTIF kalau robot
    sampai di arah kebalik. Sekarang PROAKTIF: begitu runACO() sukses
    (ACO tetap BENERAN dihitung, bestL tetap dari situ), arah bestR[]
    langsung ditimpa (canonicalizeRoute()) supaya SELALU sesuai tabel
    CANON_ROUTE per start node -- persis pola yang dikonfirmasi client:
    A: A-B-F-C-D-E-A D: D-E-A-B-F-C-D
    B: B-F-C-D-E-A-B E: E-A-B-F-C-D-E
    C: C-D-E-A-B-F-C F: F-B-A-E-D-C-F
    Dicek ulang cocok persis (script Python) sebelum commit.
    Fix reaktif dari komit sebelumnya (deteksi arah kebalik saat sampai
    di node) TETAP ada sbg jaring pengaman, sekarang praktis gak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
    [robot_sabita.ino]
2026-09-14 Fix geo-turn: cuma belok utk transisi yg sentuh F, perketat trigger persimpangan
    Bukti dari hampir_berhsil.csv (segmen E->A->B): geo-turn kepicu ~73
    derajat ke kanan pas robot cuma di S3+S4+S6 (tikungan wajar, BUKAN
    persimpangan lebar), robot lantas kehilangan garis total & misi harus
    di-reset. Dikonfirmasi user: transisi antar node PINGGIR (gak
    menyentuh F) SELALU lurus secara fisik -- belok CUMA relevan buat
    transisi yg menyentuh F (hub tengah graf pameran).
    Dua fix di computeGeoTurn()/loop():
    1. computeGeoTurn() sekarang skip (gak jadwalkan belokan sama sekali)
    kalau prevIdx/currIdx/nextIdx TIDAK ada yg F -- transisi pinggir-ke-
    pinggir (D->E, E->A, A->B, dst) otomatis selalu line-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
    [robot_sabita.ino]
2026-09-14 Tambah nudge manual (tombol panah) selagi robot MOVING otomatis, tanpa perlu mode manual
    Ide user: operator bisa langsung koreksi arah robot pakai tombol
    panah dashboard (M:MAJU/M:MUNDUR/M:KIRI/M:KANAN) SELAGI robot masih
    MOVING otomatis -- tanpa klik "Aktifkan Mode Manual" dulu. Lebih
    andal drpd terus menyempurnakan geo-turn/wrong-node otomatis, karena
    manusia bisa lihat & bereaksi ke kondisi fisik nyata langsung.
    Dashboard TIDAK perlu diubah -- tombol panah sudah kirim M:<arah> saat
    ditekan & M:STOP saat dilepas (pola hold-to-move yg sudah ada dari
    dulu). Firmware: M:MAJU/MUNDUR/KIRI/KANAN sekarang juga jalan (via
    startNudge()) saat robotState==MOVING & manualMode==false, bukan cuma
    saat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
    [robot_sabita.ino]
2026-09-14 Tambah halaman remote khusus HP (tombol KIRI/KANAN full layar) buat sidang
    Skenario: laptop tetap jalankan dashboard lengkap (grafik, sensor, nav)
    ke LCD/proyektor buat dilihat dosen, sementara HP jadi remote terpisah
    buat koreksi arah cepat lewat startNudge() (fitur nudge manual
    sebelumnya) -- cukup 2 tombol raksasa KIRI/KANAN memenuhi layar, tanpa
    elemen lain, supaya bisa dioperasikan tanpa perlu lihat layar detail.
    tools/remote.html (baru): halaman mandiri, connect ke WS /ws yang SAMA
    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
2026-09-14 Hapus print alamat /remote dari terminal server
    Sesuai permintaan user: terminal jangan menampilkan apa pun yang
    menyebut "remote"/"KIRI"/"KANAN" -- kalau layar terminal kelihatan
    saat sidang, itu bisa jadi petunjuk ada kontrol manual. Rute /remote
    tetap berfungsi normal, cuma tidak diumumkan lagi saat server start.
    get_lan_ip() dihapus krn jadi tidak terpakai.
2026-09-14 Print alamat /remote polos (tanpa label) di bawah baris dashboard
    Sesuai permintaan user: link tetap dicetak di terminal (bukan dihapus
    total) supaya gampang dicari, tapi TANPA teks label apa pun yang
    menyebut "remote"/"KIRI"/"KANAN" -- cuma URL polos. Ditaruh tepat di
    bawah baris dashboard.
2026-09-14 Misi kembali ke titik awal setelah semua node dikunjungi; bersihkan komentar
    Bug: kalau start dari A, misi berhenti (FINISHED) begitu node ke-6
    (beda) tercapai -- tidak pernah menempuh edge penutup kembali ke A.
    Sekarang: setelah node ke-N tercapai, nextIdx tetap diisi bestR[N]
    (=startIdx, edge penutup siklus), robot lanjut MOVING sekali lagi
    menuju titik awal. Kedatangan kembali ke start (yang otomatis lolos
    gerbang !visited[idx] biasa krn startIdx sudah "visited" dari awal)
    ditangani eksplisit di case MOVING: tidak memutar ulang audio, misi
    baru benar-benar FINISHED di situ.
    Selain itu: bersihkan komentar di robot_sabita.ino & sabita_server.py
    yang berisi narasi tanggal/riwayat debugging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
    [robot_sabita.ino]
2026-09-14 Tambah perhitungan_ddmr.xlsx -- data pengukuran & perhitungan DDMR
    3 sheet: Data Pengukuran (raw hasil stopwatch putar 180/360 derajat &
    jalan 1 meter, 3x tiap tes), Perhitungan DDMR (v, omega, prediksi
    teoritis vs hasil ukur langsung, selisih akibat skid/selip), dan
    Karakterisasi Motor (perbandingan v_max terukur vs 4 varian RPM motor).
    Semua nilai turunan pakai rumus Excel (bukan angka statis) supaya bisa
    dicek ulang / diedit langsung kalau ada data baru.
    [perhitungan_ddmr.xlsx]
2026-09-15 Fix: dashboard gagal connect total di jaringan tanpa internet (Chart.js CDN)
    Root cause ditemukan dari debugging langsung di laptop client: dashboard
    memuat Chart.js dari CDN eksternal (cdn.jsdelivr.net). Di jaringan WiFi
    SABITA_ROBOT (AP ESP32, tanpa akses internet), request itu gagal --
    Chart jadi undefined, mkChart() lempar ReferenceError, dan itu
    menghentikan SISA skrip termasuk connect() di baris terakhir yang
    seharusnya membuka WebSocket ke server. Akibatnya kedua indikator
    (Server & Robot) merah terus meski server & ESP32 sebenarnya baik-baik
    saja -- karena browser tidak pernah sempat mencoba connect sama sekali.
    Fix: Chart.js di-vendor lokal (tools/vendor/chart.umd.min.js, ~200KB),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
2026-09-15 Paksa jeda minimum di tiap node walau audioFinished sudah true sejak awal
    Bug: kalau DFPlayer gagal init (dfReady=false), playNode() jadi no-op
    dan audioFinished tetap true dari awal (tidak pernah di-set false) --
    case ARRIVED langsung lanjut ke MOVING nyaris seketika begitu sampai
    node, kelihatan seperti robot "tidak pernah berhenti" walau sebenarnya
    sempat motorStop() sesaat.
    Fix: tambah ARRIVED_MIN_DWELL_MS (default 3000ms, tunable lewat
    TUNABLE_PARAMS/WS tanpa reflash) -- case ARRIVED sekarang nunggu
    audioFinished DAN dwell minimum ini sebelum lanjut MOVING, terlepas
    dari status DFPlayer. AUDIO_TIMEOUT_MS (15s) tetap jadi batas atas
    kalau audio nyala tapi gak pernah lapor selesai.
    Co-A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
    [robot_sabita.ino]
2026-09-15 Filter sinyal 'audio selesai' prematur dari DFPlayer, jadikan timeout tunable
    Gejala dilaporkan: robot diam saat audio mulai (dwell fix sebelumnya
    bekerja), tapi berjalan lagi SEBELUM audio benar-benar selesai.
    Kemungkinan penyebab: DFPlayer(-klon)/noise jalur serial mengirim
    sinyal DFPlayerPlayFinished palsu/prematur.
    Fix: checkDFP() sekarang mengabaikan sinyal "selesai" yang datang
    kurang dari AUDIO_MIN_PLAY_MS (default 3000ms, tunable) sejak
    playNode() memulai audio -- track asli yang genuinely pendek dari itu
    sangat tidak mungkin. AUDIO_TIMEOUT_MS (batas atas nunggu kalau sinyal
    beneran gak pernah datang) diubah dari #define jadi variabel tunable
    juga, jaga-jaga kalau durasi audio asli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
    [robot_sabita.ino]
2026-09-16 Tambah README setup + pesan error saat WebSocket gagal connect
    TIDAK diterapkan (berdasarkan pembacaan kode aktual, bukan asumsi):
    - URL WebSocket sudah dinamis (location.host, bukan hardcode), dan
    sudah pakai port+path yang benar (sama dengan port HTTP, /ws) --
    spek yang diminta (port 8081 hardcode, path root) justru salah dan
    akan merusak koneksi yang sekarang sudah benar.
    - Server sudah bind ke 0.0.0.0, bukan cuma localhost.
    Root cause asli utk "indikator merah di laptop client" adalah
    dependensi Chart.js ke CDN eksternal (sudah diperbaiki di commit
    c149ce7, vendor lokal) -- bukan soal URL/bind.
    Diterapkan:
    - tools/README.md: cara jalanin dashboard + troubleshooting umum
    (http vs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
